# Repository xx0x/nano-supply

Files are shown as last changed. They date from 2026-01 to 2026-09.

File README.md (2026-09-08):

# Nano Supply
Compact open source Eurorack USB-C power supply. Uses USB-PD and requires at least **9V**; should work with most USB-C *fast chargers* for phones and laptops.

Lights red on unsupported USB charger, and green when all is OK.

## Specs

- up to 1250 mA @ +12V
- up to 1250 mA @ -12V
- up to 600 mA @ +5V
  
## How it looks? 

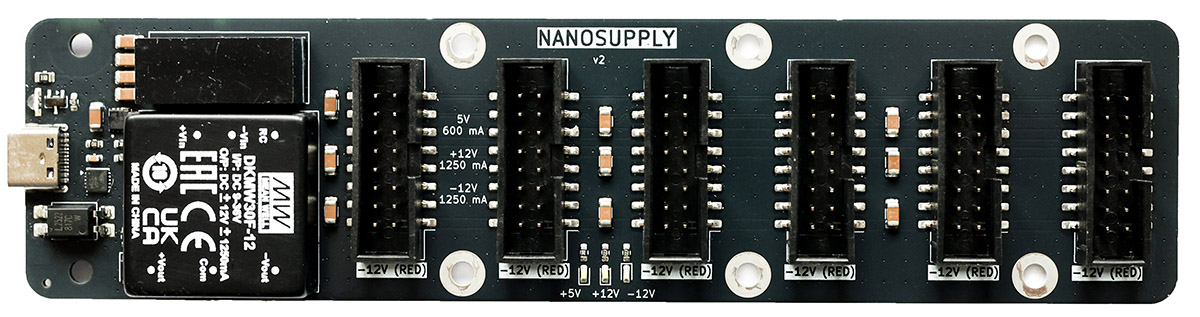
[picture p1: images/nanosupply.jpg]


## Schematics

<a href="./pcb/nano-supply-v2b/nano-supply-v2b.pdf">
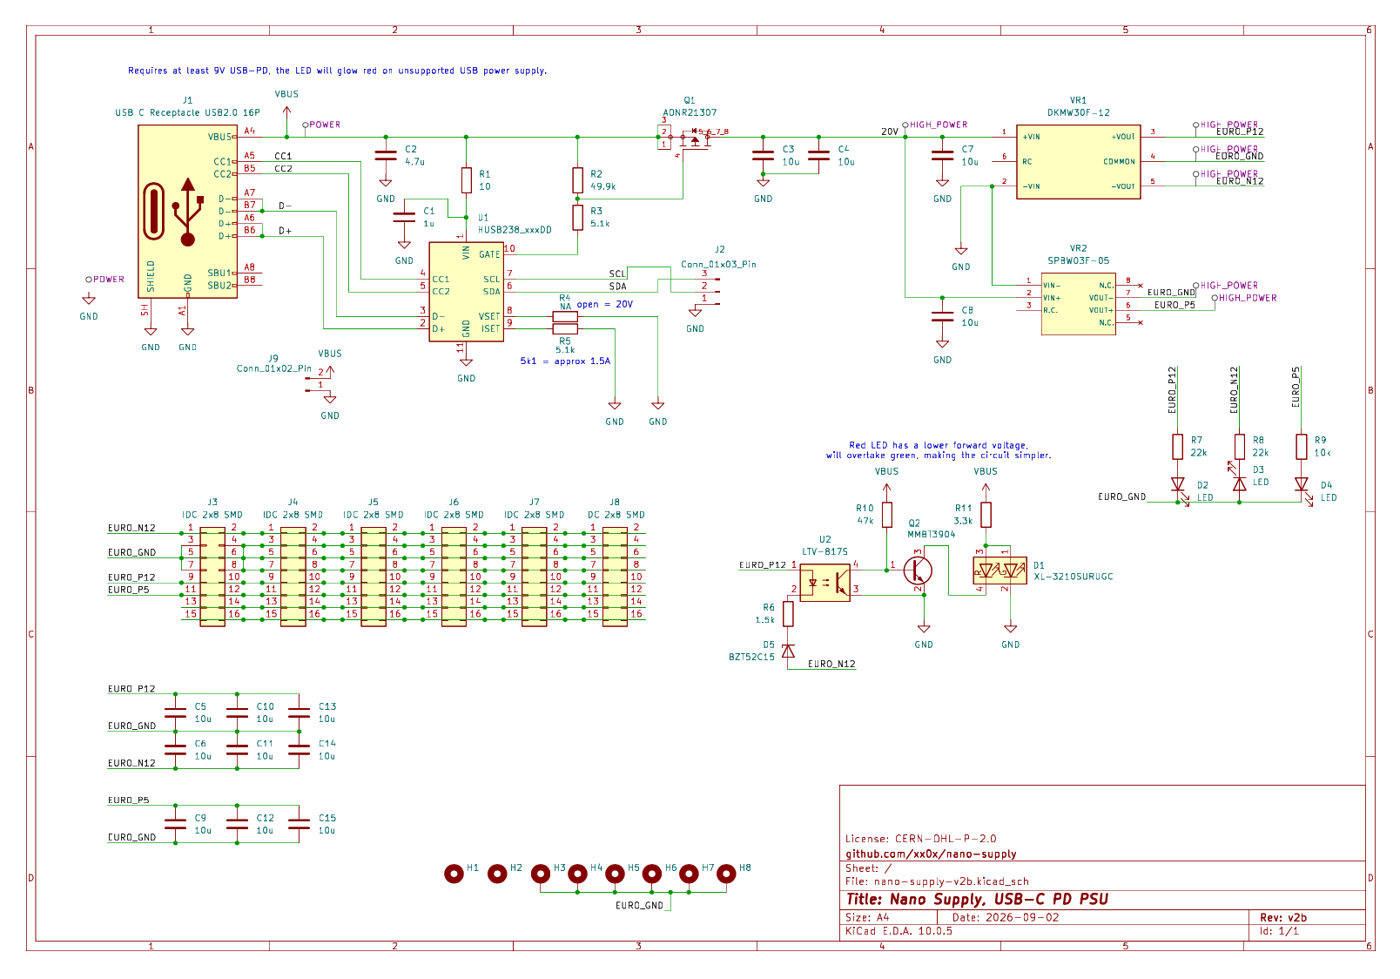
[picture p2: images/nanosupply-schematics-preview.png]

</a>

## How to get it?

You can find gerber/BOM/CPL files inside `pcb/nano-supply-v2b/jlcpcb/production_files`, the Nano Supply is not available for purchase neither as a kit or built unit at the moment.

## License

CERN-OHL-P-2.0

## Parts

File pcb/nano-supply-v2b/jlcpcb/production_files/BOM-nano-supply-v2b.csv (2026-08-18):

Comment | Designator | Footprint | LCSC | Quantity
1.5k | R6 | R_0805_2012Metric | C4310 | 1
10 | R1 | R_0603_1608Metric | C22859 | 1
10k | R9 | R_0603_1608Metric | C25804 | 1
10u | C10,C11,C12,C13,C14,C15,C3,C4,C5,C6,C7,C8,C9 | C_1206_3216Metric | C13585 | 13
1u | C1 | C_0603_1608Metric | C15849 | 1
22k | R7,R8 | R_0603_1608Metric | C31850 | 2
3.3k | R11 | R_0805_2012Metric | C26010 | 1
4.7u | C2 | C_1206_3216Metric | C29823 | 1
47k | R10 | R_0603_1608Metric | C25819 | 1
49.9k | R2 | R_0603_1608Metric | C23184 | 1
5.1k | R3,R5 | R_0603_1608Metric | C23186 | 2
AONR21307 | Q1 | TRANS_AONR21307 | C3277813 | 1
BZT52C15 | D5 | D_SOD-123 | C19077412 | 1
HUSB238_xxxDD | U1 | WDFN-10-1EP_3x3mm_P0.5mm_EP1.8x2.5mm | C7471904 | 1
IDC 2x8 SMD | J3,J4,J5,J6,J7,J8 | IDC-Header_2x08_P2.54mm_Vertical_SMD | C41376031 | 6
LED | D2,D3,D4 | LED_0603_1608Metric | C2290 | 3
LTV-817S | U2 | SMDIP-4_W9.53mm | C109227 | 1
MMBT3904 | Q2 | SOT-23 | C20526 | 1
USB_C_Receptacle_USB2.0_16P | J1 | TYPE-C-31-M-12 | C165948 | 1
XL-3210SURUGC | D1 | XL-3210SURUGC | C965883 | 1
DKMW30F-12 | VR1 | CONV_DKMW30F-12 |  | 1
Conn_01x03_Pin | J2 | TestPads_1x03_P2.54mm |  | 1
SPBW03F-05 | VR2 | SPBW03F-05_MWU |  | 1
Conn_01x02_Pin | J9 | TestPads_1x02_P2.54mm |  | 1
NA | R4 | R_0603_1608Metric |  | 1

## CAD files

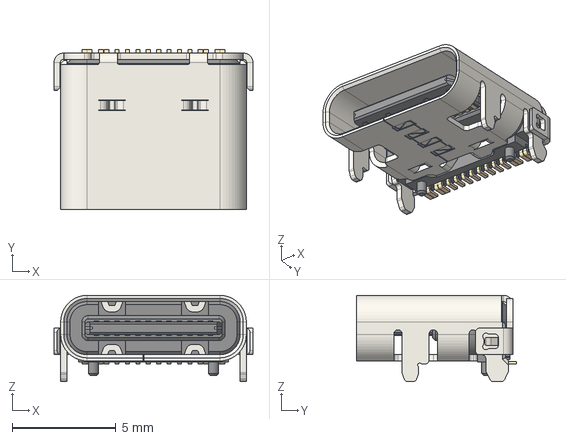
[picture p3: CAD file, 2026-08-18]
pcb/nano-supply-v2b/3dmodels/TYPE-C-31-M-12.step
9.58 x 7.71 x 4.16 mm

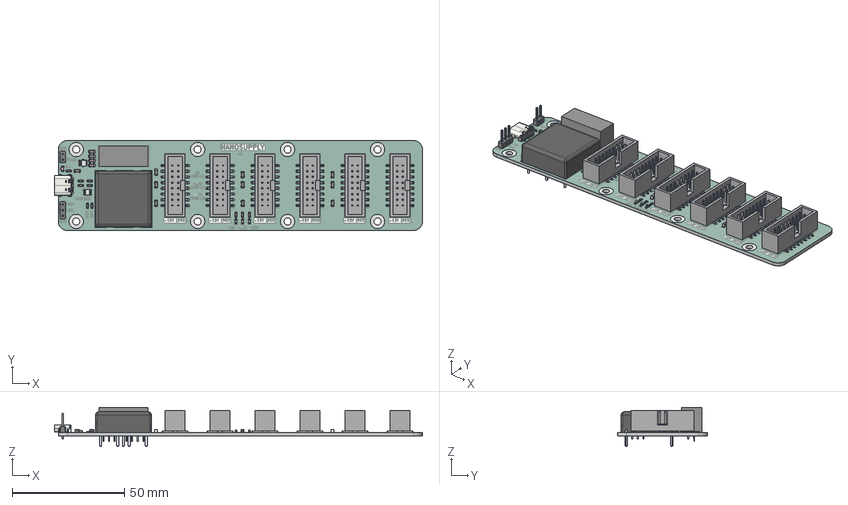
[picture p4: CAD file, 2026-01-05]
pcb/nano-supply-v2b/nano-supply-v2b.step
163.7 x 40.0 x 17.4 mm
R_0603_1608Metric x 9
thn30wi
IDC-Header_2x08_P2.54mm_Vertical_SMD x 6
LED_0603_1608Metric x 3
C_0805_2012Metric x 14
USB_C_Receptacle_GCT_USB4105-xx-A_16P_TopMnt_Horizontal
PinHeader_1x03_P2.54mm_Vertical
SPBW03F-05
PinHeader_1x02_P2.54mm_Vertical
C_0603_1608Metric
LED_Kingbright_APA1606_1.6x0.6mm_Horizontal
nano-supply-v1_pad
nano-supply-v1_silkscreen
nano-supply-v1_soldermask x 2
nano-supply-v1_PCB

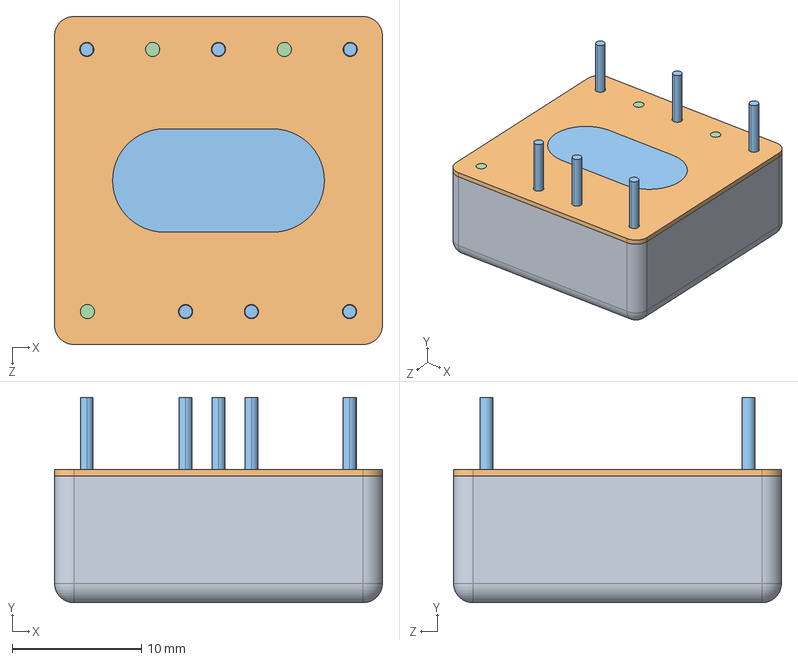
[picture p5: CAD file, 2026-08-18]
pcb/nano-supply-v2b/3dmodels/DKMW30.STEP
25.4 x 15.9 x 25.4 mm
DKMW30 CASE-1060103
DKMW30 BASE-1060103
DKMW30 PIN-1060103
DKMW30 PART1-1060103 x 3

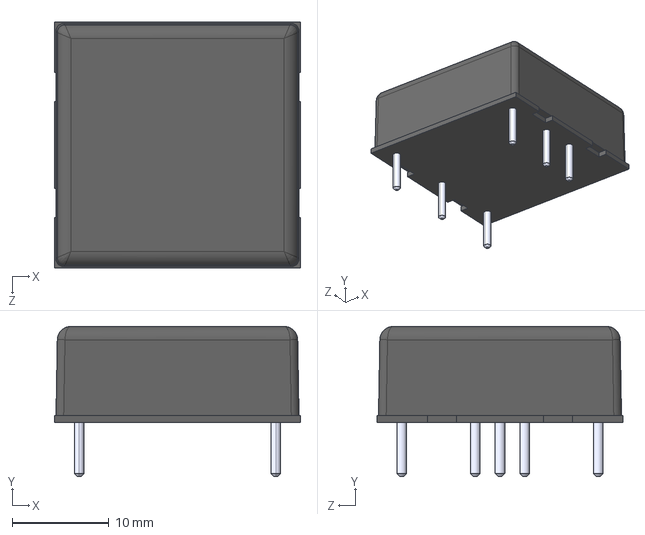
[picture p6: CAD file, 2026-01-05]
pcb/nano-supply-v2b/3dmodels/thn30wi.stp
25.4 x 15.5 x 25.4 mm

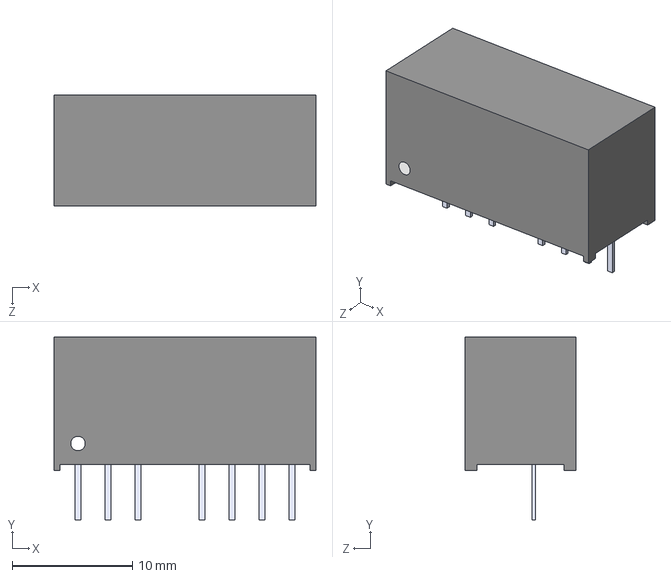
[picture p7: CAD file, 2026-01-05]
pcb/nano-supply-v2b/3dmodels/SPBW03F-05.STEP
21.8 x 15.2 x 9.20 mm

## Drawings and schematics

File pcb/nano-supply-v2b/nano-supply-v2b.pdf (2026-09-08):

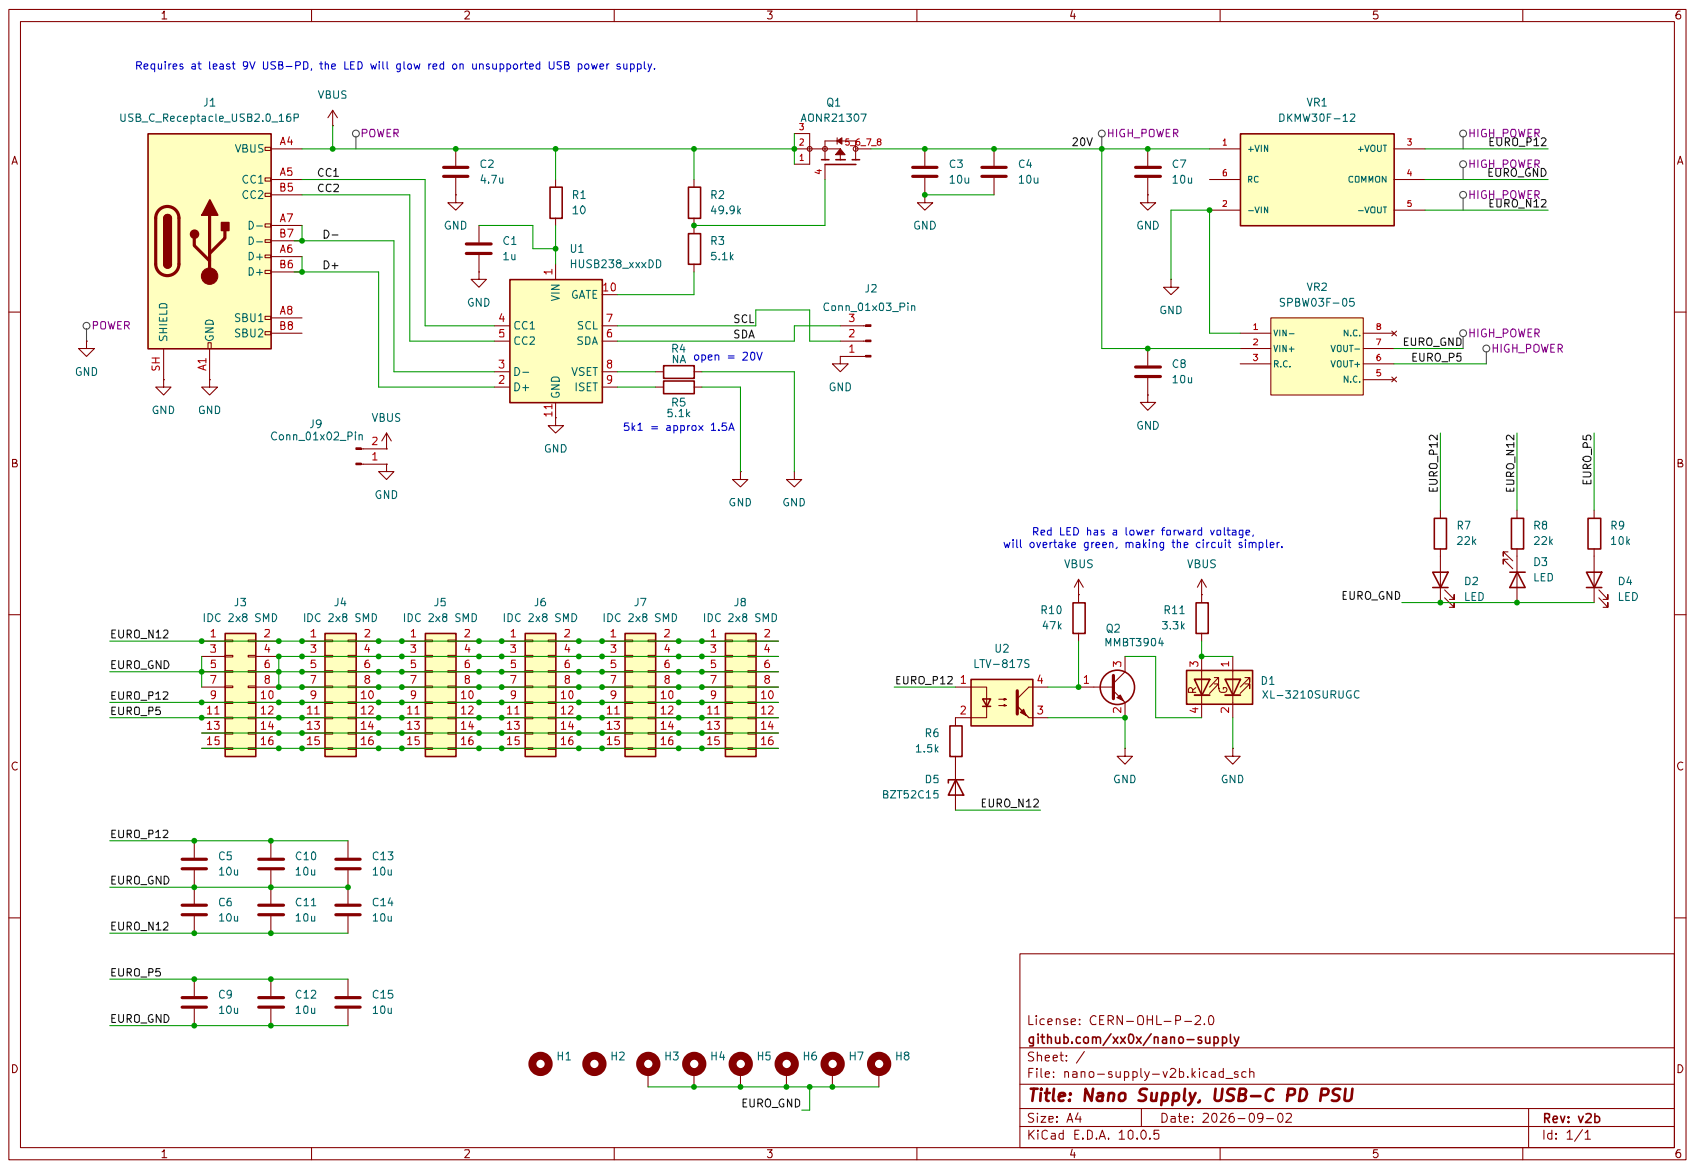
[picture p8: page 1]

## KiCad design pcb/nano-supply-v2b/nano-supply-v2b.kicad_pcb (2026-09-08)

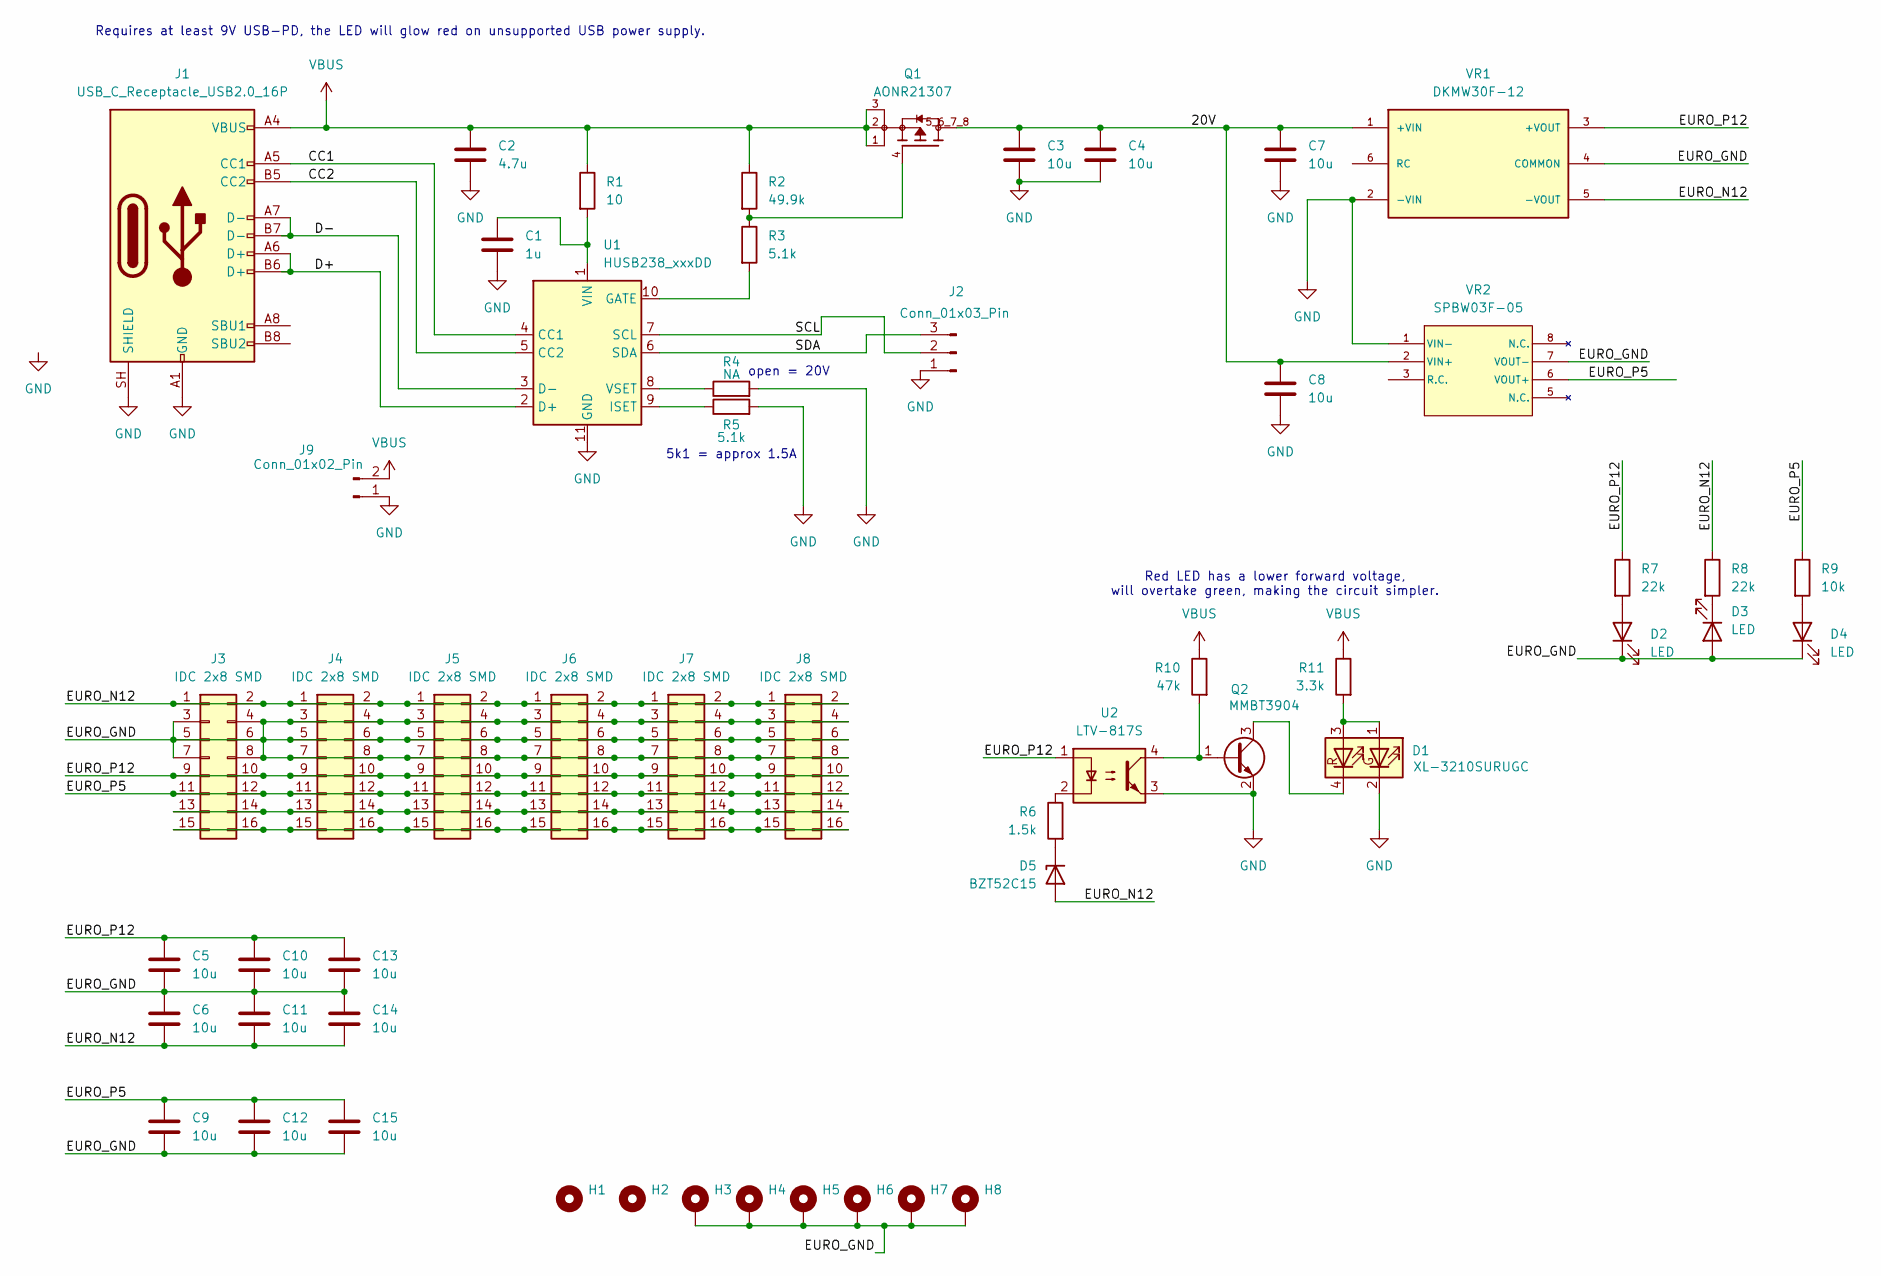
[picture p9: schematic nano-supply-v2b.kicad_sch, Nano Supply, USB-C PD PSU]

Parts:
C1: 1u; C_0603_1608Metric; LCSC C15849
C2: 4.7u; C_1206_3216Metric; LCSC C15850
C3, C4, C5, C6, C7, C8, C9, C10, C11, C12, C13, C14, C15: 10u; C_1206_3216Metric; LCSC C15850
D1: XL-3210SURUGC
D2, D3, D4: LED; LED_0603_1608Metric; LCSC C2290
D5: BZT52C15; D_SOD-123
H1, H2: MountingHole; MountingHole_3.2mm_M3
H3, H4, H5, H6, H7, H8: MountingHole_Pad; MountingHole_3.2mm_M3_Pad
J1: USB_C_Receptacle_USB2.0_16P; TYPE-C-31-M-12; LCSC C165948
J2: Conn_01x03_Pin; TestPads_1x03_P2.54mm
J3, J4, J5, J6, J7, J8: IDC 2x8 SMD; IDC-Header_2x08_P2.54mm_Vertical_SMD; LCSC C41376031
J9: Conn_01x02_Pin; TestPads_1x02_P2.54mm
Q1: AONR21307; TRANS_AONR21307; LCSC C3277813
Q2: MMBT3904; SOT-23
R1: 10; R_0603_1608Metric; LCSC C22859
R2: 49.9k; R_0603_1608Metric; LCSC C23184
R3, R5: 5.1k; R_0603_1608Metric; LCSC C23186
R4: NA; R_0603_1608Metric
R6: 1.5k; R_0805_2012Metric; LCSC C23186
R7, R8: 22k; R_0603_1608Metric; LCSC C31850
R9: 10k; R_0603_1608Metric; LCSC C31850
R10: 47k; R_0603_1608Metric; LCSC C23186
R11: 3.3k; R_0805_2012Metric; LCSC C23186
U1: HUSB238_xxxDD; WDFN-10-1EP_3x3mm_P0.5mm_EP1.8x2.5mm; LCSC C7471904
U2: LTV-817S; SMDIP-4_W9.53mm
VR1: DKMW30F-12; CONV_DKMW30F-12
VR2: SPBW03F-05; SPBW03F-05_MWU

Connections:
/20V: C3.1, C4.1, C7.1, C8.1, Q1.5_6_7_8, VR1.1 (+VIN), VR2.2 (VIN+)
/CC1: J1.A5 (CC1), U1.4 (CC1)
/CC2: J1.B5 (CC2), U1.5 (CC2)
/D+: J1.A6 (D+), J1.B6 (D+), U1.2 (D+)
/D-: J1.A7 (D-), J1.B7 (D-), U1.3 (D-)
/EURO_GND: C5.2, C6.1, C9.2, C10.2, C11.1, C12.2, C13.2, C14.1, C15.2, D2.1 (K), D3.2 (A), D4.1 (K), H3.1 (1_1), H4.1 (1_1), H5.1 (1_1), H6.1 (1_1), H7.1 (1_1), H8.1 (1_1), J3.3, J3.4, J3.5, J3.6, J3.7, J3.8, J4.3, J4.4, J4.5, J4.6, J4.7, J4.8, J5.3, J5.4, J5.5, J5.6, J5.7, J5.8, J6.3, J6.4, J6.5, J6.6, J6.7, J6.8, J7.3, J7.4, J7.5, J7.6, J7.7, J7.8, J8.3, J8.4, J8.5, J8.6, J8.7, J8.8, VR1.4 (COMMON), VR2.7 (VOUT-)
/EURO_N12: C6.2, C11.2, C14.2, D5.2 (A), J3.1, J3.2, J4.1, J4.2, J5.1, J5.2, J6.1, J6.2, J7.1, J7.2, J8.1, J8.2, R8.1, VR1.5 (-VOUT)
/EURO_P5: C9.1, C12.1, C15.1, J3.11, J3.12, J4.11, J4.12, J5.11, J5.12, J6.11, J6.12, J7.11, J7.12, J8.11, J8.12, R9.1, VR2.6 (VOUT+)
/EURO_P12: C5.1, C10.1, C13.1, J3.9, J3.10, J4.9, J4.10, J5.9, J5.10, J6.9, J6.10, J7.9, J7.10, J8.9, J8.10, R7.1, U2.1, VR1.3 (+VOUT)
/SCL: J2.2, U1.7 (SCL)
/SDA: J2.3, U1.6 (SDA)
GND: C1.2, C2.2, C3.2, C4.2, C7.2, C8.2, D1.2 (GK), J1.A1 (GND), J1.A12 (GND), J1.B1 (GND), J1.B12 (GND), J1.SH (SHIELD), J2.1, J9.1, Q2.2 (E), R4.2, R5.2, U1.11 (GND), U2.3, VR1.2 (-VIN), VR2.1 (VIN-)
unnamed: D1.1 (GA), D1.3 (RA), R11.2
unnamed: D1.4 (RK), Q2.3 (C)
unnamed: D2.2 (A), R7.2
unnamed: D3.1 (K), R8.2
unnamed: D4.2 (A), R9.2
unnamed: D5.1 (K), R6.2
unnamed: J3.13, J3.14, J4.13, J4.14, J5.13, J5.14, J6.13, J6.14, J7.13, J7.14, J8.13, J8.14
unnamed: J3.15, J3.16, J4.15, J4.16, J5.15, J5.16, J6.15, J6.16, J7.15, J7.16, J8.15, J8.16
unnamed: Q1.4, R2.2, R3.1
unnamed: Q2.1 (B), R10.2, U2.4
unnamed: R6.1, U2.2
unnamed: R3.2, U1.10 (GATE)
unnamed: R5.1, U1.9 (ISET)
unnamed: C1.1, R1.2, U1.1 (VIN)
unnamed: R4.1, U1.8 (VSET)
VBUS: C2.1, J1.A4 (VBUS), J1.A9 (VBUS), J1.B4 (VBUS), J1.B9 (VBUS), J9.2, Q1.1, Q1.2, Q1.3, R1.1, R2.1, R10.1, R11.1

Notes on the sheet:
5k1 = approx 1.5A
open = 20V
Red LED has a lower forward voltage, will overtake green, making the circuit simpler.
Requires at least 9V USB-PD, the LED will glow red on unsupported USB power supply.

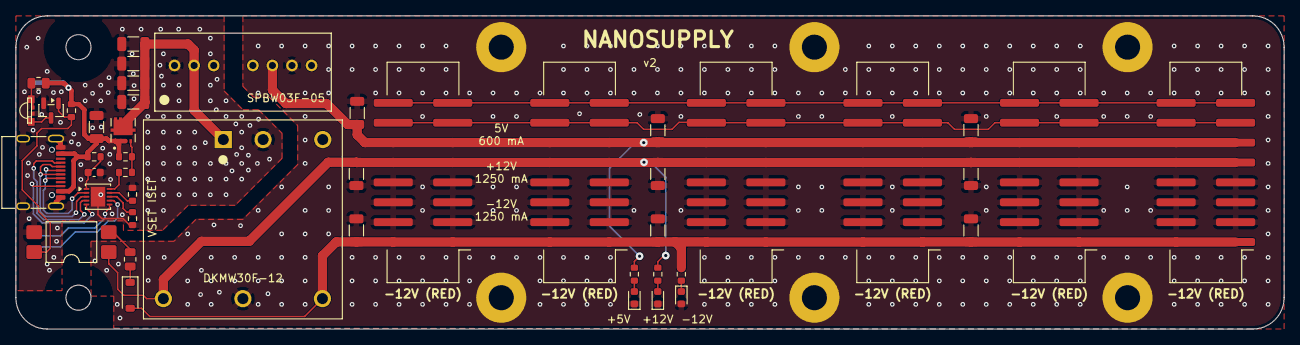
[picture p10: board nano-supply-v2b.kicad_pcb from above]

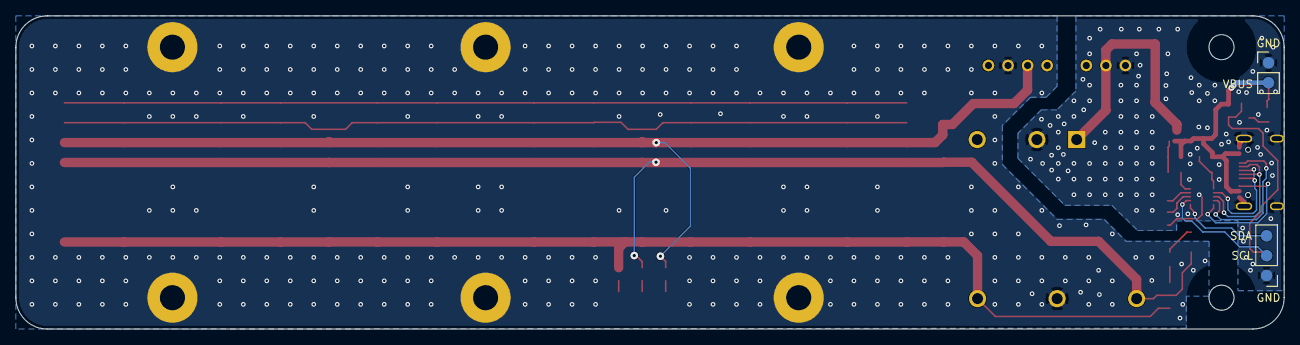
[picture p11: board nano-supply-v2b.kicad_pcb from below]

Board: 2 copper layers, 162.0 x 40.0 mm, 54 parts (2 on the bottom side), 28 nets.

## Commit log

2025-12-12 schematics, board layout
    [nano-supply-v1.kicad_pcb, nano-supply-v1.kicad_sch]
2025-12-14 stitching vias, routing tweaks
    [nano-supply-v1.kicad_pcb]
2025-12-14 add jlc mappings etc
    [BOM-nano-supply-v1.csv, nano-supply-v1.kicad_pcb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]
2025-12-14 bom, gerber updates
    [BOM-nano-supply-v1.csv, nano-supply-v1.kicad_pcb, nano-supply-v1.kicad_sch]
2026-01-05 add 3d stuff (spbw03f footprint is incorrect??)
    [SPBW03F-05.STEP, nano-supply-v1.kicad_pcb, nano-supply-v1.step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]
2026-08-18 add v2b
    [BOM-nano-supply-v1.csv, SPBW03F-05.STEP, nano-supply-v2b.kicad_pcb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]
2026-08-18 basic v2b fixes (footprints etc)
    [DKMW30.STEP, TYPE-C-31-M-12.step, nano-supply-v2b.kicad_pcb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]
2026-08-18 resistors, pdf
    [nano-supply-v2b.kicad_sch]
2026-08-18 add XL-3210SURUGC model/footprint
2026-08-18 basic power fixes
    [nano-supply-v2b.kicad_pcb, nano-supply-v2b.kicad_sch]
2026-08-18 basic board routing
    [nano-supply-v2b.kicad_pcb, nano-supply-v2b.kicad_sch]
2026-08-18 tweaks fills
    [nano-supply-v2b.kicad_pcb]
2026-08-18 board finish
    [nano-supply-v2b.kicad_pcb]
2026-08-18 jlc assignments
    [BOM-nano-supply-v2b.csv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]
2026-08-18 cleanup old files
    [BOM-nano-supply-v1.csv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]
2026-09-02 readme, license
    [nano-supply-v2b.kicad_sch]
2026-09-08 add schematics notes
    [nano-supply-v2b.kicad_pcb, nano-supply-v2b.kicad_sch]
2026-09-08 add schematic link to the readme
